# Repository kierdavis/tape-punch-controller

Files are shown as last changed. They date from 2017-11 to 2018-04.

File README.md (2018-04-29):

# Tape Punch Controller

This repository contains the source code and CAD designs used for my university third year individual project.

The project involves designing a system that can interface a restored [Teletype BPRE-type High Speed Tape Punch][tapepunch] to a modern computer over USB.

## Repository Layout

- [`/firmware`][repo-firmware]: source code of the firmware running on the microcontroller
- [`/pcb`][repo-pcb]: design files for the PCB used in the device
- [`/mechanical`][repo-mechanical]: design files for various laser-cut parts

[tapepunch]: http://www.computinghistory.org.uk/det/2312/teletype-brpe-20-high-speed-tape-punch/
[repo-firmware]: https://github.com/kierdavis/tape-punch-controller/tree/master/firmware
[repo-pcb]: https://github.com/kierdavis/tape-punch-controller/tree/master/pcb
[repo-mechanical]: https://github.com/kierdavis/tape-punch-controller/tree/master/mechanical

## Branches

Two main Git branches are used with this repository: `master` and `stable`. New development occurs on `master`; when it has been tested and is deemed ready to ship to the client, it is merged into `stable`. `stable` should be a reflection of the version currently in use by the client.

## License

The contents of this repository are licensed under the terms of the MIT license. See the [LICENSE](LICENSE) file for more details.

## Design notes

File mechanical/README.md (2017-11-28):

# Tape Punch Controller Laser Cutter Designs

These files are in DXF format, readable by [librecad][librecad]. Some designs also have older versions created in 
[FreeCAD][freecad], which I stopped using since it crashed too much.

Part designs in this directory are:

* `back-panel`: a cover for the cavity in the rear of the tape punch's case through which the power and data cables are 
wired. This is to reduce the risk of injury resulting from exposed live wiring.
* `psu-cover`: a minimal cover for the exposed live terminals on the [28V power supply unit][psu]. This is only for 
development; suitable protection will be built into the final product's case design.

[psu]: https://uk.rs-online.com/web/p/-/7772869/
[librecad]: http://librecad.org/cms/home.html
[freecad]: https://www.freecadweb.org/

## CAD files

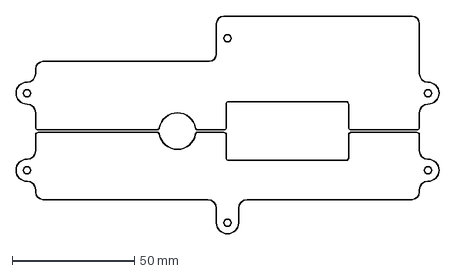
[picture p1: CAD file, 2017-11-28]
mechanical/back-panel/back-panel-rev3.dxf
173.0 x 89.0 mm

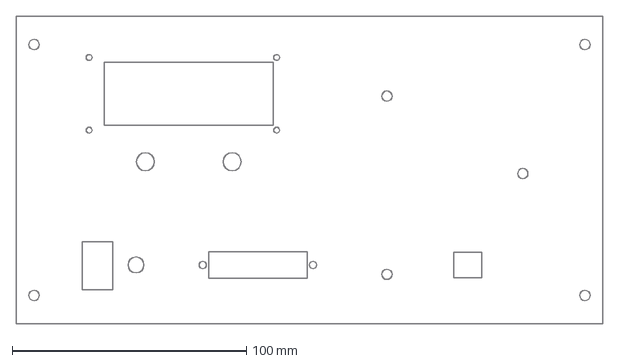
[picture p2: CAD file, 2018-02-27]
mechanical/chassis/front.dxf
250.0 x 131.0 mm

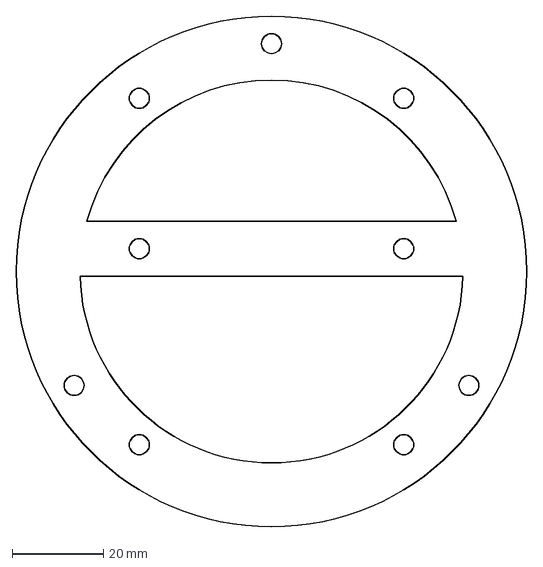
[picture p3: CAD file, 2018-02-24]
mechanical/pcb-holder/pcb-holder.dxf
112.0 x 112.0 mm

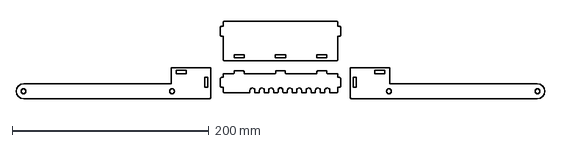
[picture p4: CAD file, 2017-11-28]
mechanical/psu-cover/psu-cover-rev1.dxf
537.0 x 78.5 mm

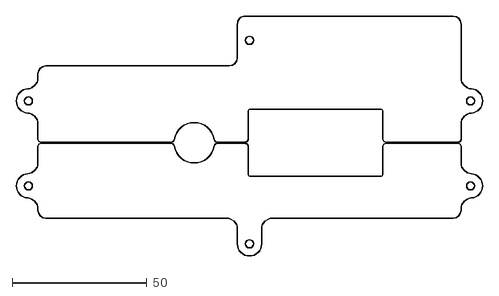
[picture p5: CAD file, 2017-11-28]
mechanical/back-panel/back-panel-rev2-export.dxf
173.0 x 89.0

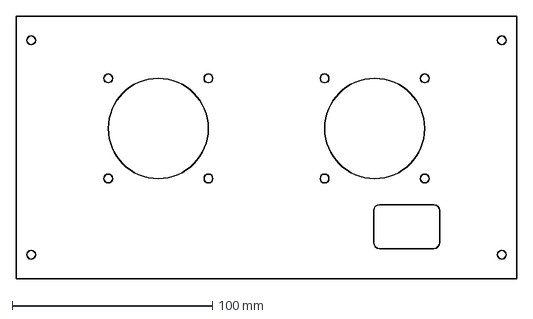
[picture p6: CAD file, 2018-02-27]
mechanical/chassis/rear.dxf
250.0 x 131.0 mm

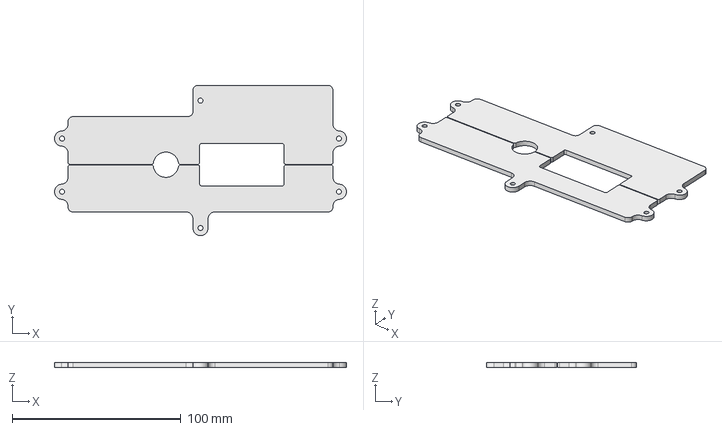
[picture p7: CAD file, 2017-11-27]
mechanical/back-panel/back-panel-rev2.fcstd
173.0 x 89.0 x 3.00 mm

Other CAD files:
mechanical/back-panel/back-panel-rev1.fcstd

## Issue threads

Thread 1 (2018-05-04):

Fix regulator footprint on PCB

kierdavis, 2018-05-04:
The PCB currently uses a standard TO-220 footprint for the 3.3V and 15V regulators, but the components are actually quite a bit larger. They could still be soldered, albeit at a funky angle since one side has to sit on top of the decoupling capacitor.

To fix this, a custom footprint with adequate clearance should be used, and the PCB layout adjusted appropriately.

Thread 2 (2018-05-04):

Fix LCD contrast voltage

kierdavis, 2018-05-04:
As a result of someone's impeccable datasheet-reading skills, the circuit currently allows the LCD's contrast voltage (`Vdd - V0`) to be adjusted between 0V and 3.3V, but the [datasheet](http://docs-europe.electrocomponents.com/webdocs/1548/0900766b815480c9.pdf) says the LCD expects between 4.3V and 4.7V.

This could be fixed by increasing Vdd (e.g. adding a 5V regulator) or decreasing the minimum V0 (needs a negative voltage supply).

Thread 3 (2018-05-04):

Use LCD's status flag rather than assuming all commands have a fixed duration

kierdavis, 2018-05-04:
This may allow some commands to complete earlier than they do currently, and would generally be considered a better approach.

Doing this involves changing the circuit such that the LCD's R/W pin is no longer tied to ground, but to a microcontroller output. This allows the LCD to be read from as well as written to. The [datasheet](https://www.newhavendisplay.com/app_notes/SPLC780D.pdf) then says that the bit 7 of the byte received from the LCD with `RS = 0` and `R/W = 1` is a 1 if the LCD is busy and will not currently accept commands, or a 0 if the LCD is idle and can accept commands.

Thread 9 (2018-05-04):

Design and implement a streaming interface

kierdavis, 2018-05-04:
Using Mass Storage conveniently allows the device to be used without needing to install any custom software on the PC it is used with; however it sets a hard limit on the size of a file that can be transferred. Implementing a stream-based interface (e.g. USB CDC or a custom device class) would step around this problem, and would likely facilitate implementing #8.

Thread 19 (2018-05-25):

Remove USB sense circuitry

kierdavis, 2018-05-25:
Ultimately this wasn't needed since LUFA does a good enough job of detecting when the USB cable is plugged/unplugged. It's therefore unnecessary and should be removed from the PCB.

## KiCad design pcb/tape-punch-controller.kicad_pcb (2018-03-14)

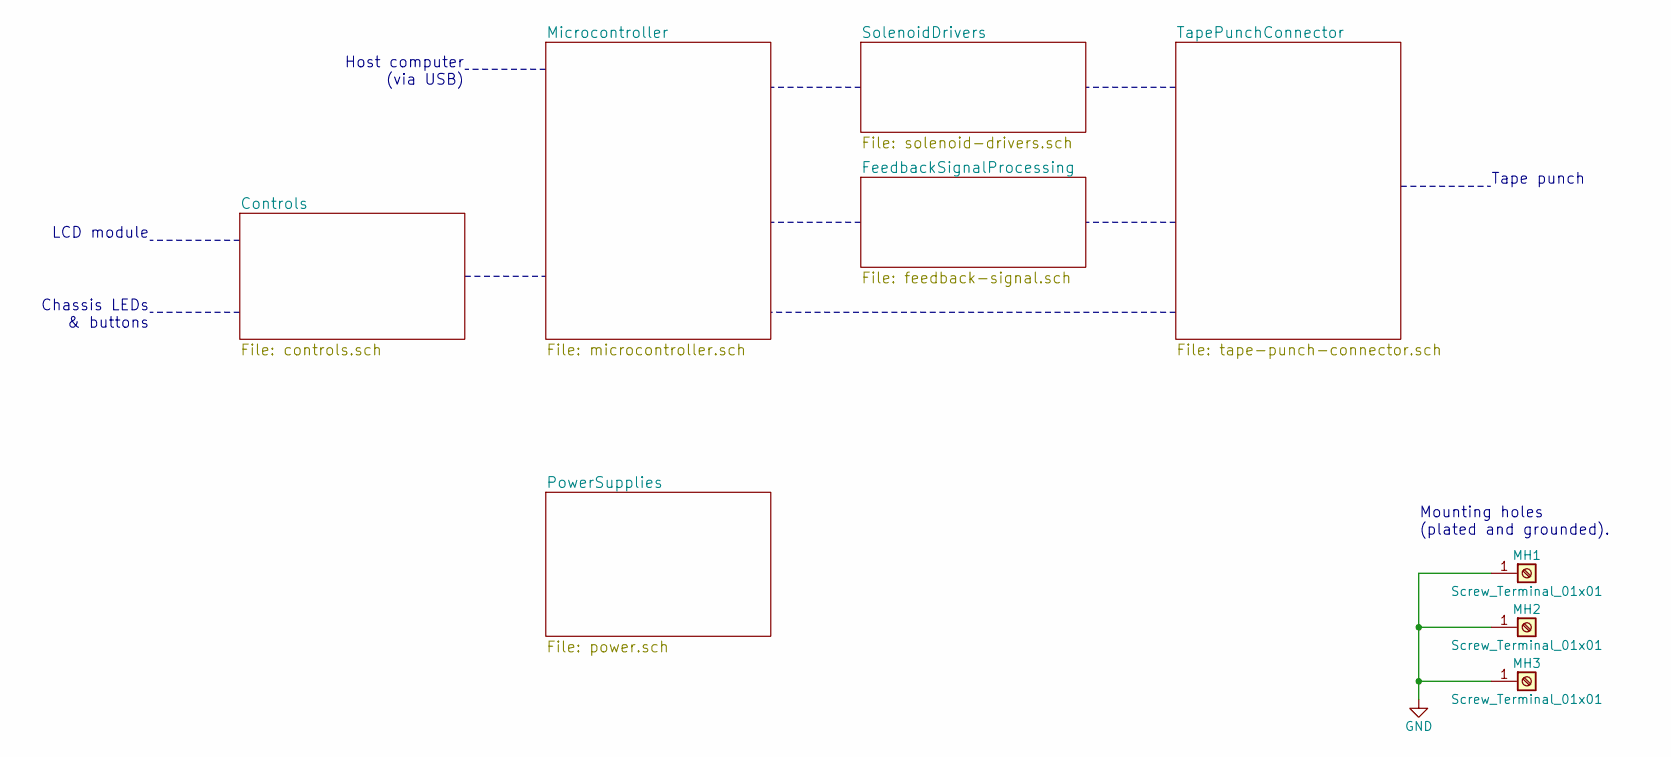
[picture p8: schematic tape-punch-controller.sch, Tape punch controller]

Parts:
MH1, MH2, MH3: Screw_Terminal_01x01; MountingHole_4.3mm_M4_Pad

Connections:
GND: MH1.1, MH2.1, MH3.1; also elsewhere on the board

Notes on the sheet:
Mounting holes (plated and grounded).
LCD module
Chassis LEDs & buttons
Host computer (via USB)
Tape punch

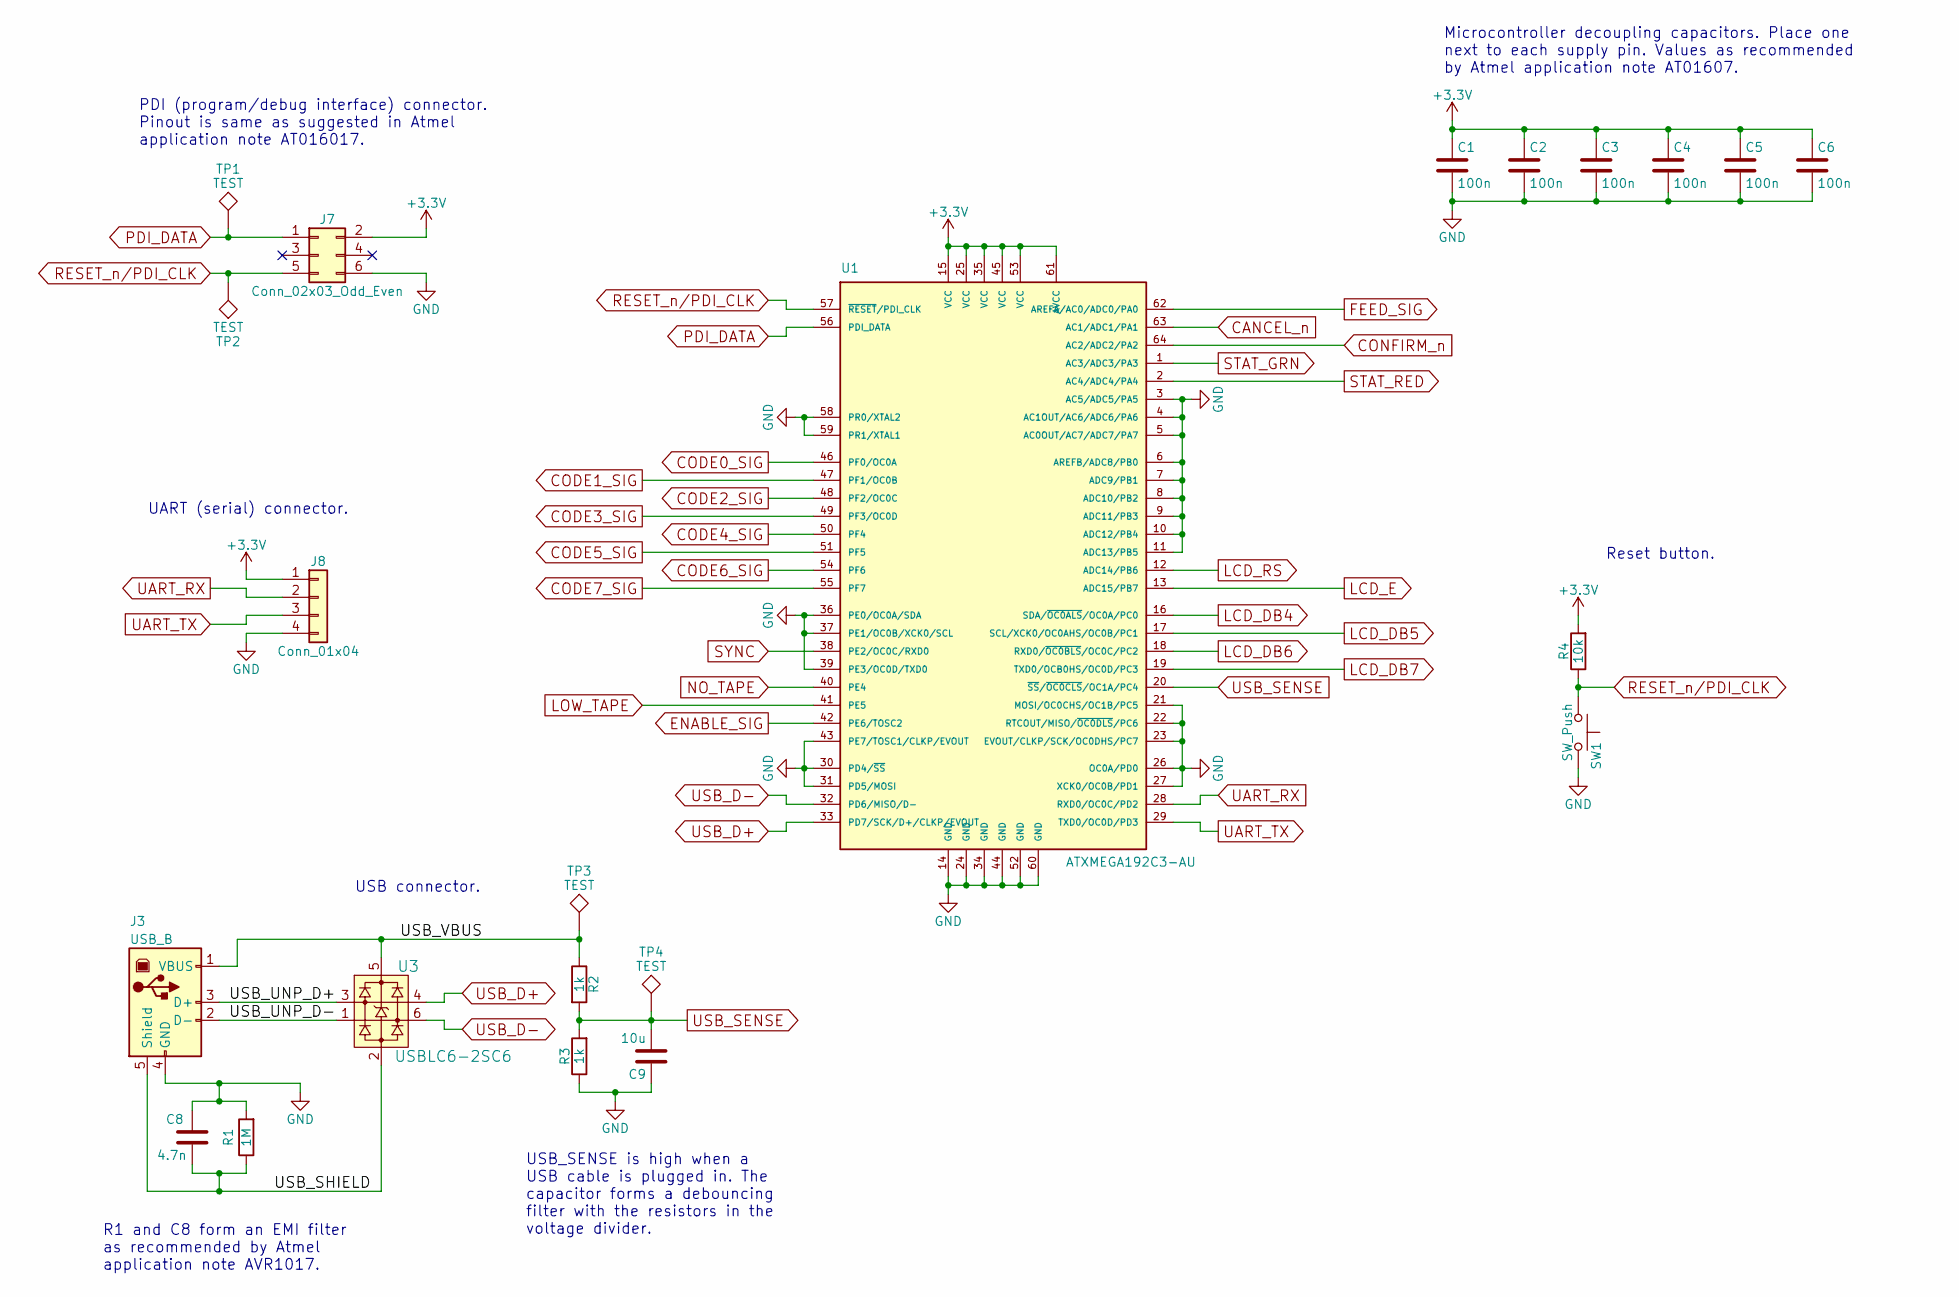
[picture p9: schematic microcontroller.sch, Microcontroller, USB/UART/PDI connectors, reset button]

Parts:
C1, C2, C3, C4, C5, C6: 100n; C_0805_HandSoldering
C8: 4.7n; C_0805_HandSoldering
C9: 10u; C_1206_HandSoldering
J3: USB_B; Multicomp_MC32597
J7: Conn_02x03_Odd_Even; Pin_Header_Straight_2x03_Pitch2.54mm
J8: Conn_01x04; Pin_Header_Straight_1x04_Pitch2.54mm
R1: 1M; R_0805_HandSoldering
R2, R3: 1k; R_0805_HandSoldering
R4: 10k; R_0805_HandSoldering
SW1: SW_Push; SW_Tactile_SPST_Angled_PTS645Vx58-2LFS
TP1, TP2, TP3, TP4: TEST; Measurement_Point_Round-SMD-Pad_Small
U1: ATXMEGA192C3-AU; TQFP-64_14x14mm_Pitch0.8mm
U3: USBLC6-2SC6; SOT-23-6_Handsoldering

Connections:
+3V3: C1.1, C2.1, C3.1, C4.1, C5.1, C6.1, J7.2, J8.1, R4.2, U1.15 (VCC), U1.25 (VCC), U1.35 (VCC), U1.45 (VCC), U1.53 (VCC), U1.61 (AVCC); also elsewhere on the board
/Microcontroller/USB_SHIELD: C8.2, J3.5 (Shield), R1.1, U3.2 (GND)
/Microcontroller/USB_UNP_D+: J3.3 (D+), U3.3 (D+)
/Microcontroller/USB_UNP_D-: J3.2 (D-), U3.1 (D-)
/Microcontroller/USB_VBUS: J3.1 (VBUS), R2.1, TP3.1, U3.5 (VBUS)
CANCEL_n: U1.63 (AC1/ADC1/PA1); also elsewhere on the board
CODE0_SIG: U1.46 (PF0/OC0A); also elsewhere on the board
CODE1_SIG: U1.47 (PF1/OC0B); also elsewhere on the board
CODE2_SIG: U1.48 (PF2/OC0C); also elsewhere on the board
CODE3_SIG: U1.49 (PF3/OC0D); also elsewhere on the board
CODE4_SIG: U1.50 (PF4); also elsewhere on the board
CODE5_SIG: U1.51 (PF5); also elsewhere on the board
CODE6_SIG: U1.54 (PF6); also elsewhere on the board
CODE7_SIG: U1.55 (PF7); also elsewhere on the board
CONFIRM_n: U1.64 (AC2/ADC2/PA2); also elsewhere on the board
ENABLE_SIG: U1.42 (PE6/TOSC2); also elsewhere on the board
FEED_SIG: U1.62 (AREFA/AC0/ADC0/PA0); also elsewhere on the board
GND: C1.2, C2.2, C3.2, C4.2, C5.2, C6.2, C8.1, C9.1, J3.4 (GND), J7.6, J8.4, R1.2, R3.1, SW1.2, U1.3 (AC5/ADC5/PA5), U1.4 (AC1OUT/AC6/ADC6/PA6), U1.5 (AC0OUT/AC7/ADC7/PA7), U1.6 (AREFB/ADC8/PB0), U1.7 (ADC9/PB1), U1.8 (ADC10/PB2), U1.9 (ADC11/PB3), U1.10 (ADC12/PB4), U1.11 (ADC13/PB5), U1.14 (GND), U1.21 (MOSI/OC0CHS/OC1B/PC5), U1.22 (RTCOUT/MISO/~OC0DLS~/PC6), U1.23 (EVOUT/CLKP/SCK/OC0DHS/PC7), U1.24 (GND), U1.26 (OC0A/PD0), U1.27 (XCK0/OC0B/PD1), U1.30 (PD4/~SS~), U1.31 (PD5/MOSI), U1.34 (GND), U1.36 (PE0/OC0A/SDA), U1.37 (PE1/OC0B/XCK0/SCL), U1.39 (PE3/OC0D/TXD0), U1.43 (PE7/TOSC1/CLKP/EVOUT), U1.44 (GND), U1.52 (GND), U1.58 (PR0/XTAL2), U1.59 (PR1/XTAL1), U1.60 (GND); also elsewhere on the board
LCD_DB4: U1.16 (SDA/~OC0ALS~/OC0A/PC0); also elsewhere on the board
LCD_DB5: U1.17 (SCL/XCK0/OC0AHS/OC0B/PC1); also elsewhere on the board
LCD_DB6: U1.18 (RXD0/~OC0BLS~/OC0C/PC2); also elsewhere on the board
LCD_DB7: U1.19 (TXD0/OCB0HS/OC0D/PC3); also elsewhere on the board
LCD_E: U1.13 (ADC15/PB7); also elsewhere on the board
LCD_RS: U1.12 (ADC14/PB6); also elsewhere on the board
LOW_TAPE: U1.41 (PE5); also elsewhere on the board
NO_TAPE: U1.40 (PE4); also elsewhere on the board
PDI_DATA: J7.1, TP1.1, U1.56 (PDI_DATA)
RESET_n/PDI_CLK: J7.5, R4.1, SW1.1, TP2.1, U1.57 (~RESET~/PDI_CLK)
STAT_GRN: U1.1 (AC3/ADC3/PA3); also elsewhere on the board
STAT_RED: U1.2 (AC4/ADC4/PA4); also elsewhere on the board
SYNC: U1.38 (PE2/OC0C/RXD0); also elsewhere on the board
UART_RX: J8.2, U1.28 (RXD0/OC0C/PD2)
UART_TX: J8.3, U1.29 (TXD0/OC0D/PD3)
USB_D+: U1.33 (PD7/SCK/D+/CLKP/EVOUT), U3.4 (D+)
USB_D-: U1.32 (PD6/MISO/D-), U3.6 (D-)
USB_SENSE: C9.2, R2.2, R3.2, TP4.1, U1.20 (~SS~/~OC0CLS~/OC1A/PC4)

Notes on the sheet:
Microcontroller decoupling capacitors. Place one next to each supply pin. Values as recommended by Atmel application note AT01607.
UART (serial) connector.
PDI (program/debug interface) connector. Pinout is same as suggested in Atmel application note AT016017.
USB connector.
USB_SENSE is high when a USB cable is plugged in. The capacitor forms a debouncing filter with the resistors in the voltage divider.
R1 and C8 form an EMI filter as recommended by Atmel application note AVR1017.
Reset button.

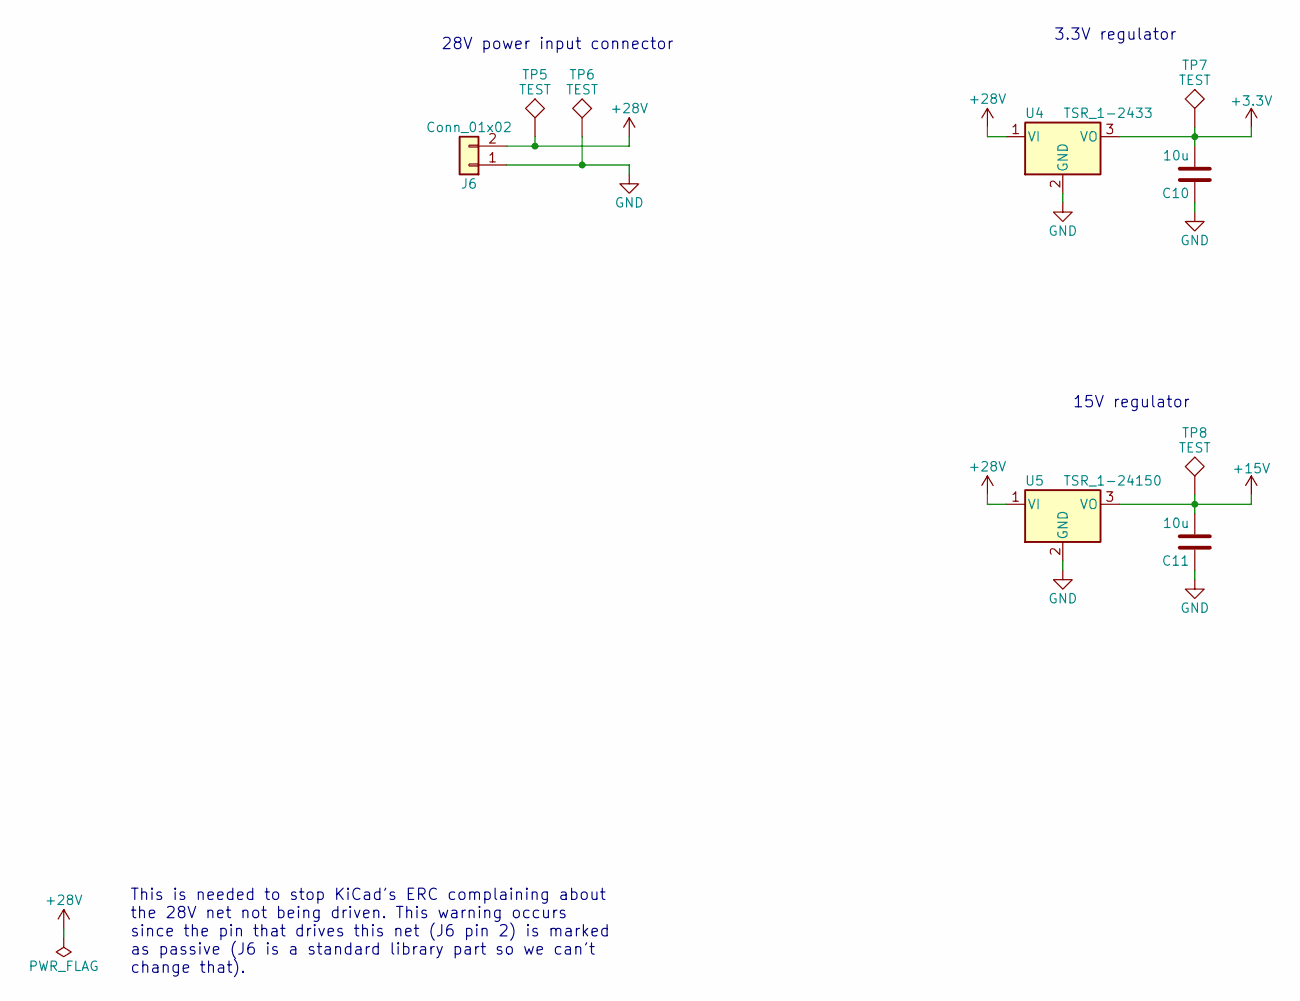
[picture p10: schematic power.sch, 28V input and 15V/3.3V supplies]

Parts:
C10, C11: 10u; C_1206_HandSoldering
J6: Conn_01x02; Multicomp_MC000048
TP5, TP6, TP7, TP8: TEST; Measurement_Point_Round-SMD-Pad_Small
U4: TSR_1-2433; TO-220-3_Vertical
U5: TSR_1-24150; TO-220-3_Vertical

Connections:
+3V3: C10.2, TP7.1, U4.3 (VO); also elsewhere on the board
+15V: C11.2, TP8.1, U5.3 (VO); also elsewhere on the board
+28V: J6.2, TP5.1, U4.1 (VI), U5.1 (VI); also elsewhere on the board
GND: C10.1, C11.1, J6.1, TP6.1, U4.2 (GND), U5.2 (GND); also elsewhere on the board

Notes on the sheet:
28V power input connector
3.3V regulator
15V regulator
This is needed to stop KiCad's ERC complaining about the 28V net not being driven. This warning occurs since the pin that drives this net (J6 pin 2) is marked as passive (J6 is a standard library part so we can't change that).

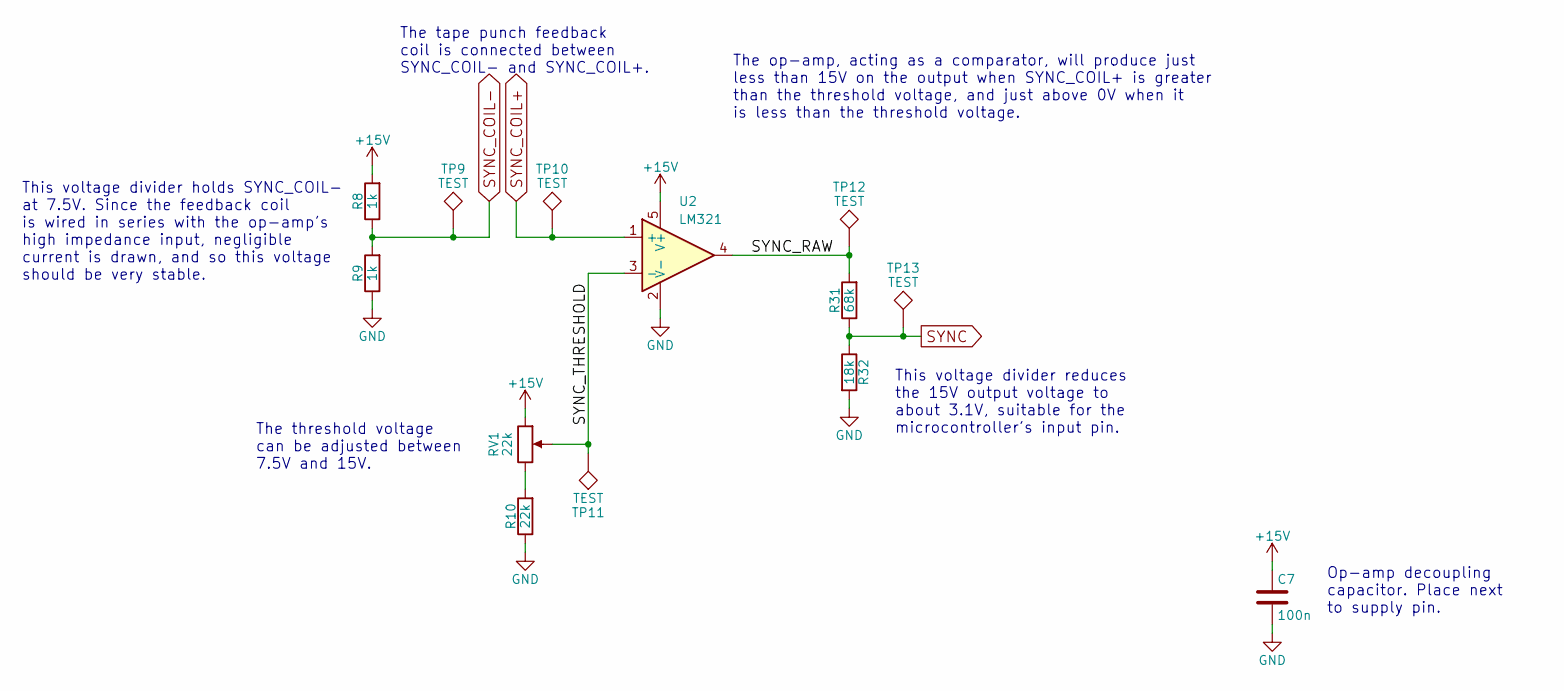
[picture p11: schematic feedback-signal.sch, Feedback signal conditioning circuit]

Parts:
C7: 100n; C_0805_HandSoldering
R8, R9: 1k; R_0805_HandSoldering
R10: 22k; R_0805_HandSoldering
R31: 68k; R_0805_HandSoldering
R32: 18k; R_0805_HandSoldering
RV1: 22k; Citec_CB10LV103M
TP9, TP10, TP11, TP12, TP13: TEST; Measurement_Point_Round-SMD-Pad_Small
U2: LM321; SOT-23-5_HandSoldering

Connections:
+15V: C7.1, R8.2, RV1.1, U2.5 (V+); also elsewhere on the board
/FeedbackSignalProcessing/SYNC_RAW: R31.2, TP12.1, U2.4
/FeedbackSignalProcessing/SYNC_THRESHOLD: RV1.2, TP11.1, U2.3 (-)
GND: C7.2, R9.1, R10.1, R32.2, U2.2 (V-); also elsewhere on the board
unnamed: R10.2, RV1.3
SYNC: R31.1, R32.1, TP13.1; also elsewhere on the board
SYNC_COIL+: TP10.1, U2.1 (+); also elsewhere on the board
SYNC_COIL-: R8.1, R9.2, TP9.1; also elsewhere on the board

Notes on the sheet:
Op-amp decoupling capacitor. Place next to supply pin.
The tape punch feedback coil is connected between SYNC_COIL- and SYNC_COIL+.
This voltage divider holds SYNC_COIL- at 7.5V. Since the feedback coil is wired in series with the op-amp's high impedance input, negligible current is drawn, and so this voltage should be very stable.
The threshold voltage can be adjusted between 7.5V and 15V.
The op-amp, acting as a comparator, will produce just less than 15V on the output when SYNC_COIL+ is greater than the threshold voltage, and just above 0V when it is less than the threshold voltage.
This voltage divider reduces the 15V output voltage to about 3.1V, suitable for the microcontroller's input pin.

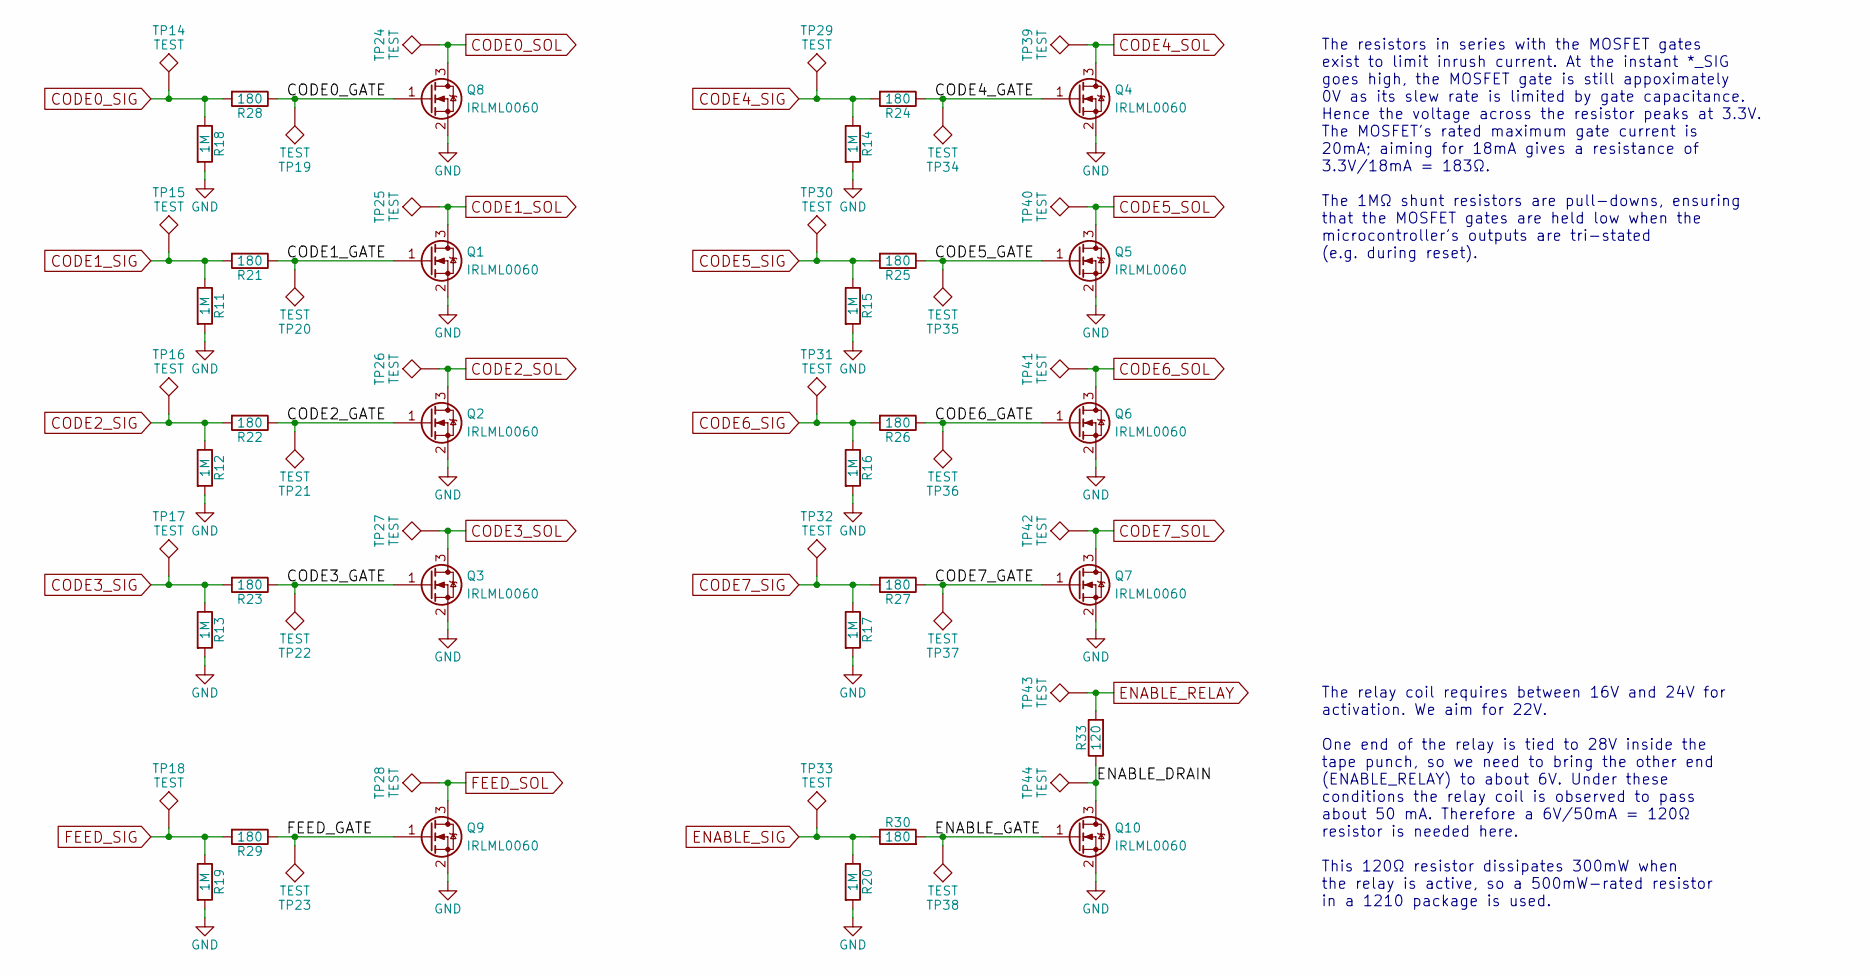
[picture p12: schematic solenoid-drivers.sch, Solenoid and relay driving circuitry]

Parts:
Q1, Q2, Q3, Q4, Q5, Q6, Q7, Q8, Q9, Q10: IRLML0060; SOT-23_Handsoldering
R11, R12, R13, R14, R15, R16, R17, R18, R19, R20: 1M; R_0805_HandSoldering
R21, R22, R23, R24, R25, R26, R27, R28, R29, R30: 180; R_0805_HandSoldering
R33: 120; R_1210_HandSoldering
TP14, TP15, TP16, TP17, TP18, TP19, TP20, TP21, TP22, TP23, TP24, TP25, TP26, TP27, TP28, TP29, TP30, TP31, TP32, TP33, TP34, TP35, TP36, TP37, TP38, TP39, TP40, TP41, TP42, TP43, TP44: TEST; Measurement_Point_Round-SMD-Pad_Small

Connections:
/SolenoidDrivers/CODE0_GATE: Q8.1 (G), R28.1, TP19.1
/SolenoidDrivers/CODE1_GATE: Q1.1 (G), R21.1, TP20.1
/SolenoidDrivers/CODE2_GATE: Q2.1 (G), R22.1, TP21.1
/SolenoidDrivers/CODE3_GATE: Q3.1 (G), R23.1, TP22.1
/SolenoidDrivers/CODE4_GATE: Q4.1 (G), R24.1, TP34.1
/SolenoidDrivers/CODE5_GATE: Q5.1 (G), R25.1, TP35.1
/SolenoidDrivers/CODE6_GATE: Q6.1 (G), R26.1, TP36.1
/SolenoidDrivers/CODE7_GATE: Q7.1 (G), R27.1, TP37.1
/SolenoidDrivers/ENABLE_DRAIN: Q10.3 (D), R33.1, TP44.1
/SolenoidDrivers/ENABLE_GATE: Q10.1 (G), R30.2, TP38.1
/SolenoidDrivers/FEED_GATE: Q9.1 (G), R29.1, TP23.1
CODE0_SIG: R18.1, R28.2, TP14.1; also elsewhere on the board
CODE0_SOL: Q8.3 (D), TP24.1; also elsewhere on the board
CODE1_SIG: R11.1, R21.2, TP15.1; also elsewhere on the board
CODE1_SOL: Q1.3 (D), TP25.1; also elsewhere on the board
CODE2_SIG: R12.1, R22.2, TP16.1; also elsewhere on the board
CODE2_SOL: Q2.3 (D), TP26.1; also elsewhere on the board
CODE3_SIG: R13.1, R23.2, TP17.1; also elsewhere on the board
CODE3_SOL: Q3.3 (D), TP27.1; also elsewhere on the board
CODE4_SIG: R14.1, R24.2, TP29.1; also elsewhere on the board
CODE4_SOL: Q4.3 (D), TP39.1; also elsewhere on the board
CODE5_SIG: R15.1, R25.2, TP30.1; also elsewhere on the board
CODE5_SOL: Q5.3 (D), TP40.1; also elsewhere on the board
CODE6_SIG: R16.1, R26.2, TP31.1; also elsewhere on the board
CODE6_SOL: Q6.3 (D), TP41.1; also elsewhere on the board
CODE7_SIG: R17.1, R27.2, TP32.1; also elsewhere on the board
CODE7_SOL: Q7.3 (D), TP42.1; also elsewhere on the board
ENABLE_RELAY: R33.2, TP43.1; also elsewhere on the board
ENABLE_SIG: R20.1, R30.1, TP33.1; also elsewhere on the board
FEED_SIG: R19.1, R29.2, TP18.1; also elsewhere on the board
FEED_SOL: Q9.3 (D), TP28.1; also elsewhere on the board
GND: Q1.2 (S), Q2.2 (S), Q3.2 (S), Q4.2 (S), Q5.2 (S), Q6.2 (S), Q7.2 (S), Q8.2 (S), Q9.2 (S), Q10.2 (S), R11.2, R12.2, R13.2, R14.2, R15.2, R16.2, R17.2, R18.2, R19.2, R20.2; also elsewhere on the board

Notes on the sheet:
The resistors in series with the MOSFET gates exist to limit inrush current. At the instant *_SIG goes high, the MOSFET gate is still appoximately 0V as its slew rate is limited by gate capacitance. Hence the voltage across the resistor peaks at 3.3V. The MOSFET's rated maximum gate current is 20mA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
The relay coil requires between 16V and 24V for activation. We aim for 22V. One end of the relay is tied to 28V inside the tape punch, so we need to bring the other end (ENABLE_RELAY) to about 6V. Under these conditions the relay coil is observed to pass about 50 mA. Therefore a 6V/50mA = 120Ω resi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

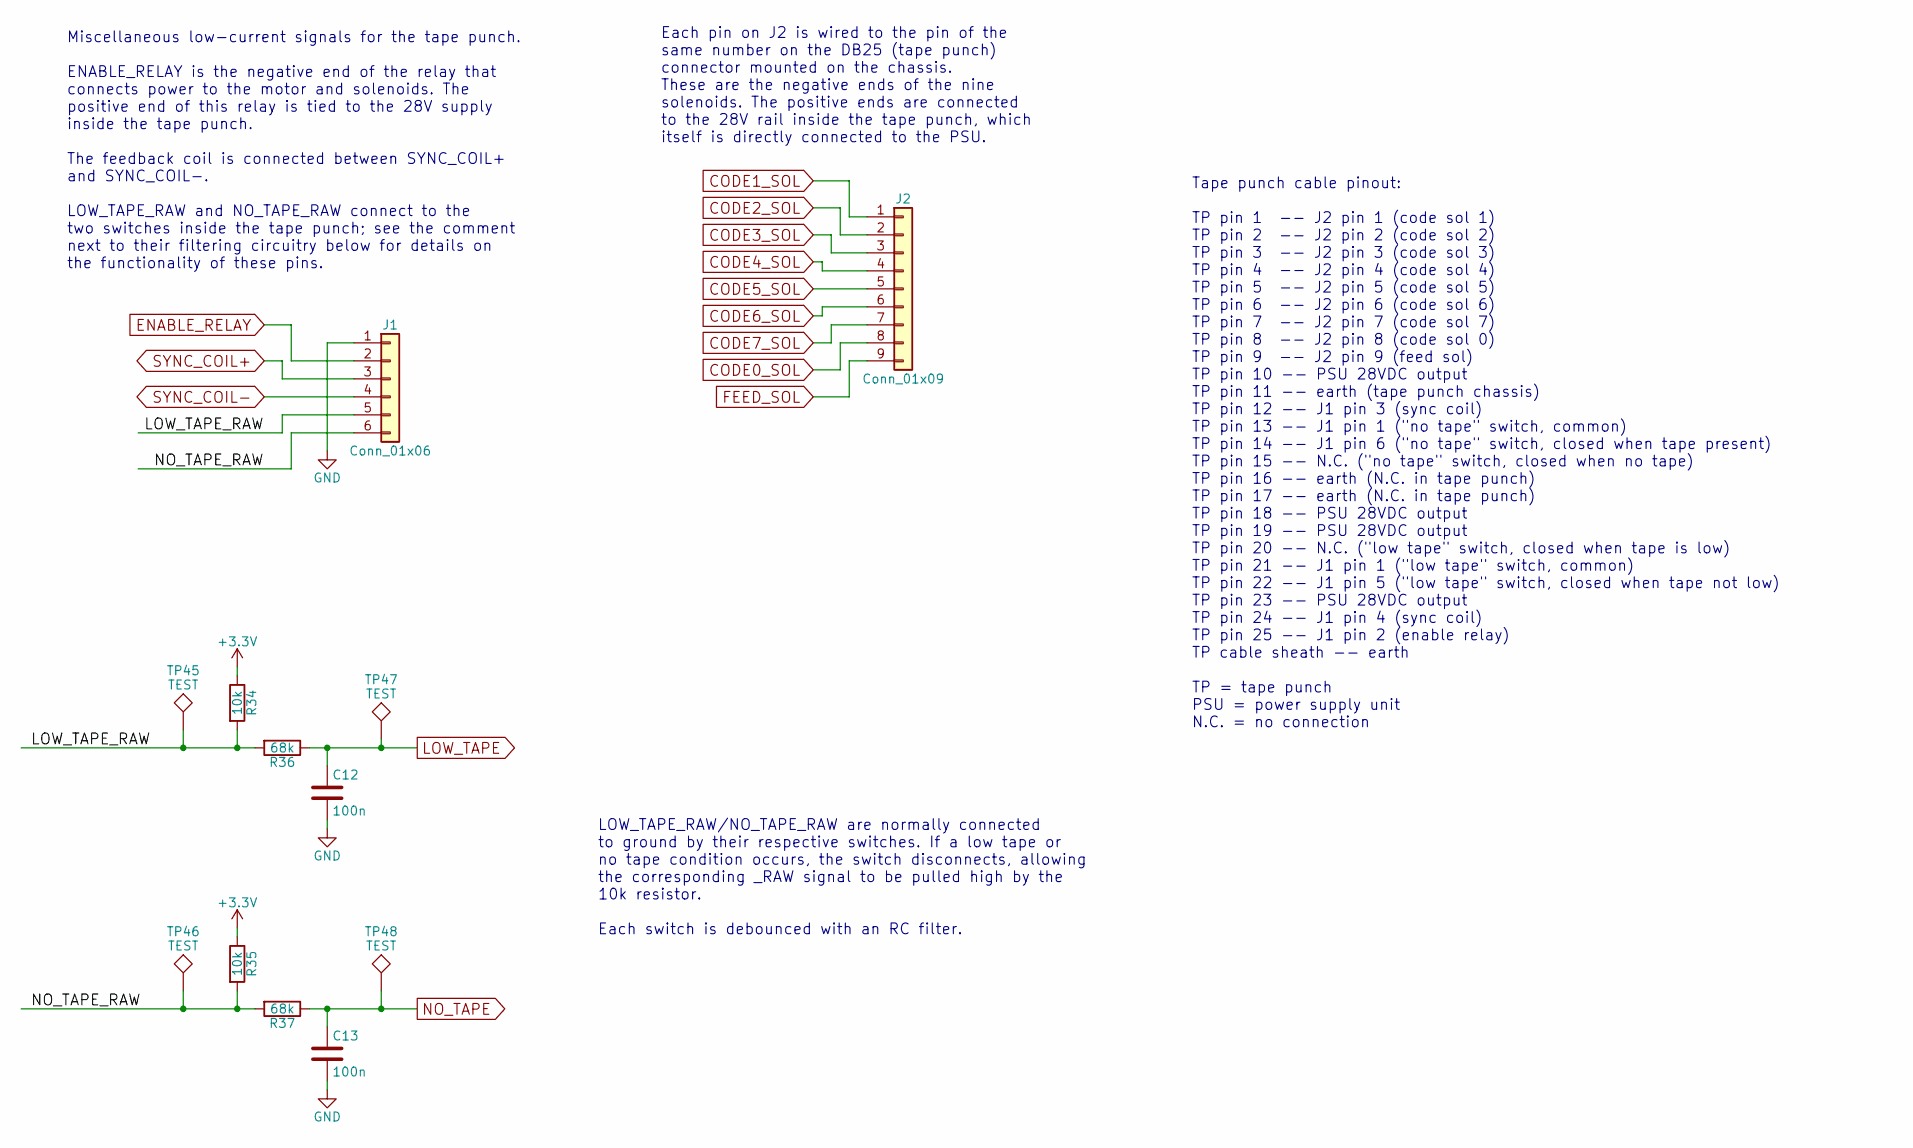
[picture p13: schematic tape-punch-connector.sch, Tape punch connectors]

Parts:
C12, C13: 100n; C_0805_HandSoldering
J1: Conn_01x06; Amphenol_T821106A1S100CEU
J2: Conn_01x09; Weidmuller_1234610000
R34, R35: 10k; R_0805_HandSoldering
R36, R37: 68k; R_0805_HandSoldering
TP45, TP46, TP47, TP48: TEST; Measurement_Point_Round-SMD-Pad_Small

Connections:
+3V3: R34.1, R35.1; also elsewhere on the board
/TapePunchConnector/LOW_TAPE_RAW: J1.5, R34.2, R36.2, TP45.1
/TapePunchConnector/NO_TAPE_RAW: J1.6, R35.2, R37.2, TP46.1
CODE0_SOL: J2.8; also elsewhere on the board
CODE1_SOL: J2.1; also elsewhere on the board
CODE2_SOL: J2.2; also elsewhere on the board
CODE3_SOL: J2.3; also elsewhere on the board
CODE4_SOL: J2.4; also elsewhere on the board
CODE5_SOL: J2.5; also elsewhere on the board
CODE6_SOL: J2.6; also elsewhere on the board
CODE7_SOL: J2.7; also elsewhere on the board
ENABLE_RELAY: J1.2; also elsewhere on the board
FEED_SOL: J2.9; also elsewhere on the board
GND: C12.2, C13.2, J1.1; also elsewhere on the board
LOW_TAPE: C12.1, R36.1, TP47.1; also elsewhere on the board
NO_TAPE: C13.1, R37.1, TP48.1; also elsewhere on the board
SYNC_COIL+: J1.3; also elsewhere on the board
SYNC_COIL-: J1.4; also elsewhere on the board

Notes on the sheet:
LOW_TAPE_RAW/NO_TAPE_RAW are normally connected to ground by their respective switches. If a low tape or no tape condition occurs, the switch disconnects, allowing the corresponding _RAW signal to be pulled high by the 10k resistor. Each switch is debounced with an RC filter.
Each pin on J2 is wired to the pin of the same number on the DB25 (tape punch) connector mounted on the chassis. These are the negative ends of the nine solenoids. The positive ends are connected to the 28V rail inside the tape punch, which itself is directly connected to the PSU.
Tape punch cable pinout: TP pin 1 -- J2 pin 1 (code sol 1) TP pin 2 -- J2 pin 2 (code sol 2) TP pin 3 -- J2 pin 3 (code sol 3) TP pin 4 -- J2 pin 4 (code sol 4) TP pin 5 -- J2 pin 5 (code sol 5) TP pin 6 -- J2 pin 6 (code sol 6) TP pin 7 -- J2 pin 7 (code sol 7) TP pin 8 -- J2 pin 8 (code sol 0) TP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
Miscellaneous low-current signals for the tape punch. ENABLE_RELAY is the negative end of the relay that connects power to the motor and solenoids. The positive end of this relay is tied to the 28V supply inside the tape punch. The feedback coil is connected between SYNC_COIL+ and SYNC_COIL-. LOW_T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

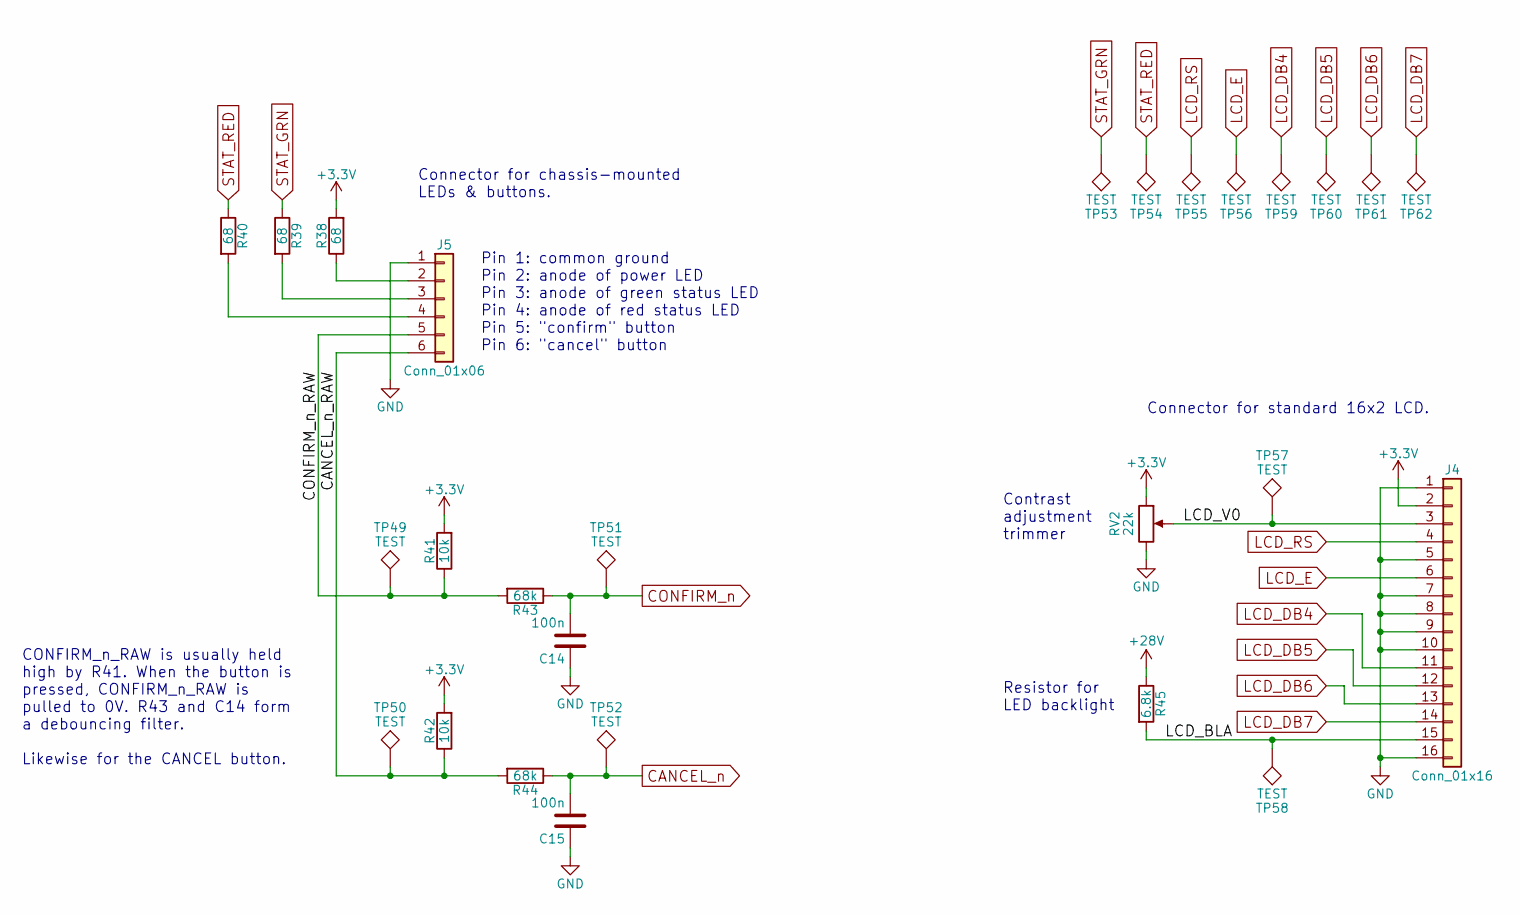
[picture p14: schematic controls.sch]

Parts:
C14, C15: 100n; C_0805_HandSoldering
J4: Conn_01x16; Amphenol_T821116A1S100CEU
J5: Conn_01x06; Amphenol_T821106A1S100CEU
R38, R39, R40: 68; R_0805_HandSoldering
R41, R42: 10k; R_0805_HandSoldering
R43, R44: 68k; R_0805_HandSoldering
R45: 6.8k; R_0805_HandSoldering
RV2: 22k; Citec_CB10LV103M
TP49, TP50, TP51, TP52, TP53, TP54, TP55, TP56, TP57, TP58, TP59, TP60, TP61, TP62: TEST; Measurement_Point_Round-SMD-Pad_Small

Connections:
+3V3: J4.2, R38.2, R41.2, R42.2, RV2.1; also elsewhere on the board
+28V: R45.1; also elsewhere on the board
/Controls/CANCEL_n_RAW: J5.6, R42.1, R44.2, TP50.1
/Controls/CONFIRM_n_RAW: J5.5, R41.1, R43.2, TP49.1
/Controls/LCD_BLA: J4.15, R45.2, TP58.1
/Controls/LCD_V0: J4.3, RV2.2, TP57.1
CANCEL_n: C15.2, R44.1, TP52.1; also elsewhere on the board
CONFIRM_n: C14.2, R43.1, TP51.1; also elsewhere on the board
GND: C14.1, C15.1, J4.1, J4.5, J4.7, J4.8, J4.9, J4.10, J4.16, J5.1, RV2.3; also elsewhere on the board
LCD_DB4: J4.11, TP59.1; also elsewhere on the board
LCD_DB5: J4.12, TP60.1; also elsewhere on the board
LCD_DB6: J4.13, TP61.1; also elsewhere on the board
LCD_DB7: J4.14, TP62.1; also elsewhere on the board
LCD_E: J4.6, TP56.1; also elsewhere on the board
LCD_RS: J4.4, TP55.1; also elsewhere on the board
unnamed: J5.2, R38.1
unnamed: J5.3, R39.2
unnamed: J5.4, R40.2
STAT_GRN: R39.1, TP53.1; also elsewhere on the board
STAT_RED: R40.1, TP54.1; also elsewhere on the board

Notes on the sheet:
Contrast adjustment trimmer
Resistor for LED backlight
Connector for standard 16x2 LCD.
Connector for chassis-mounted LEDs & buttons.
Pin 1: common ground Pin 2: anode of power LED Pin 3: anode of green status LED Pin 4: anode of red status LED Pin 5: "confirm" button Pin 6: "cancel" button
CONFIRM_n_RAW is usually held high by R41. When the button is pressed, CONFIRM_n_RAW is pulled to 0V. R43 and C14 form a debouncing filter. Likewise for the CANCEL button.

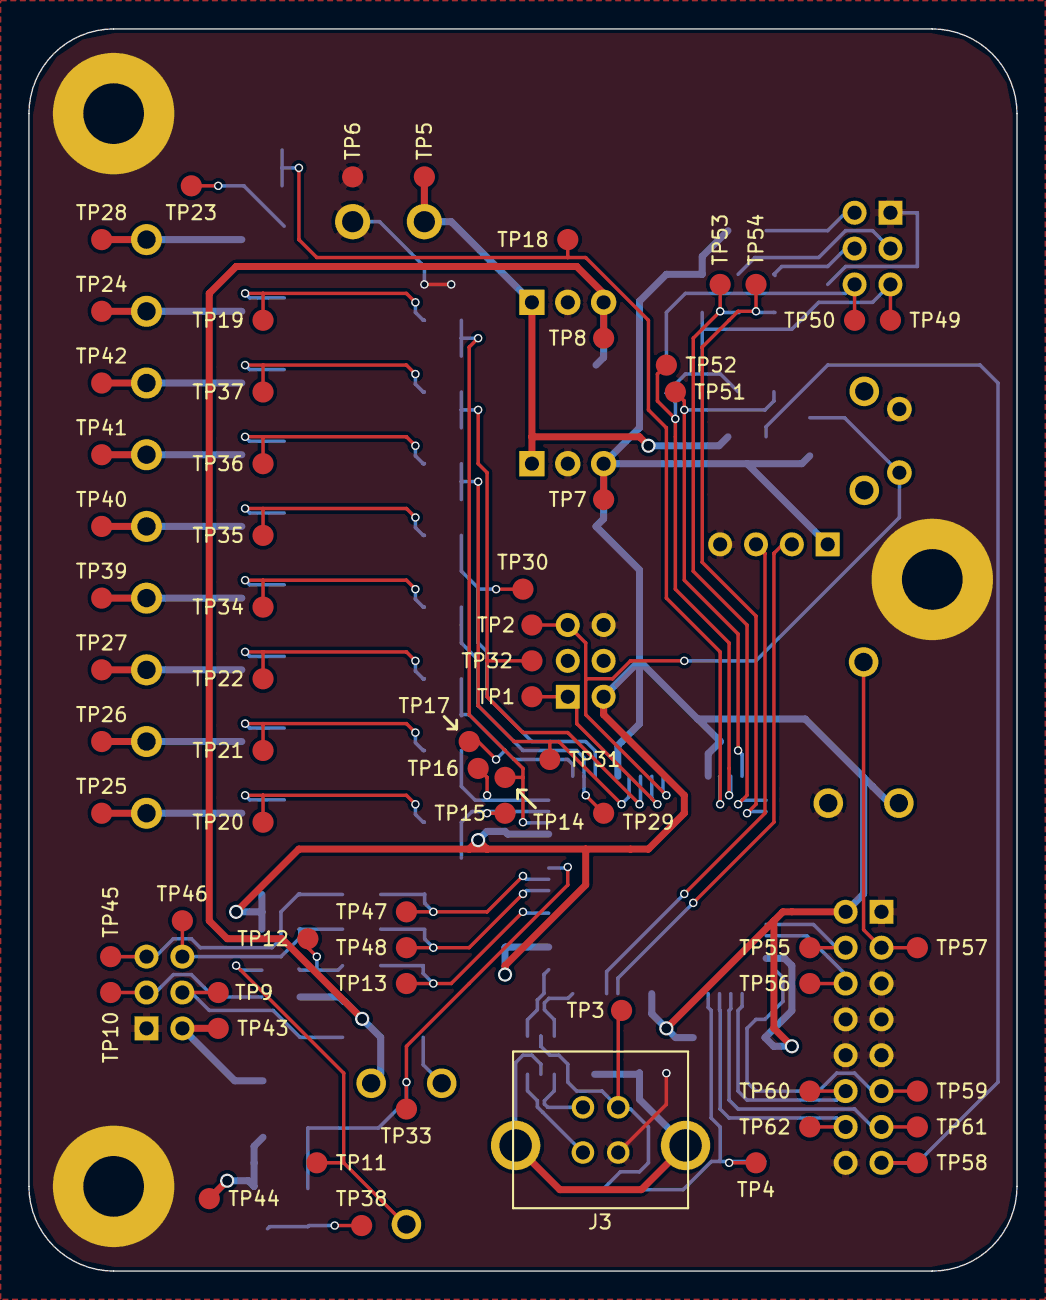
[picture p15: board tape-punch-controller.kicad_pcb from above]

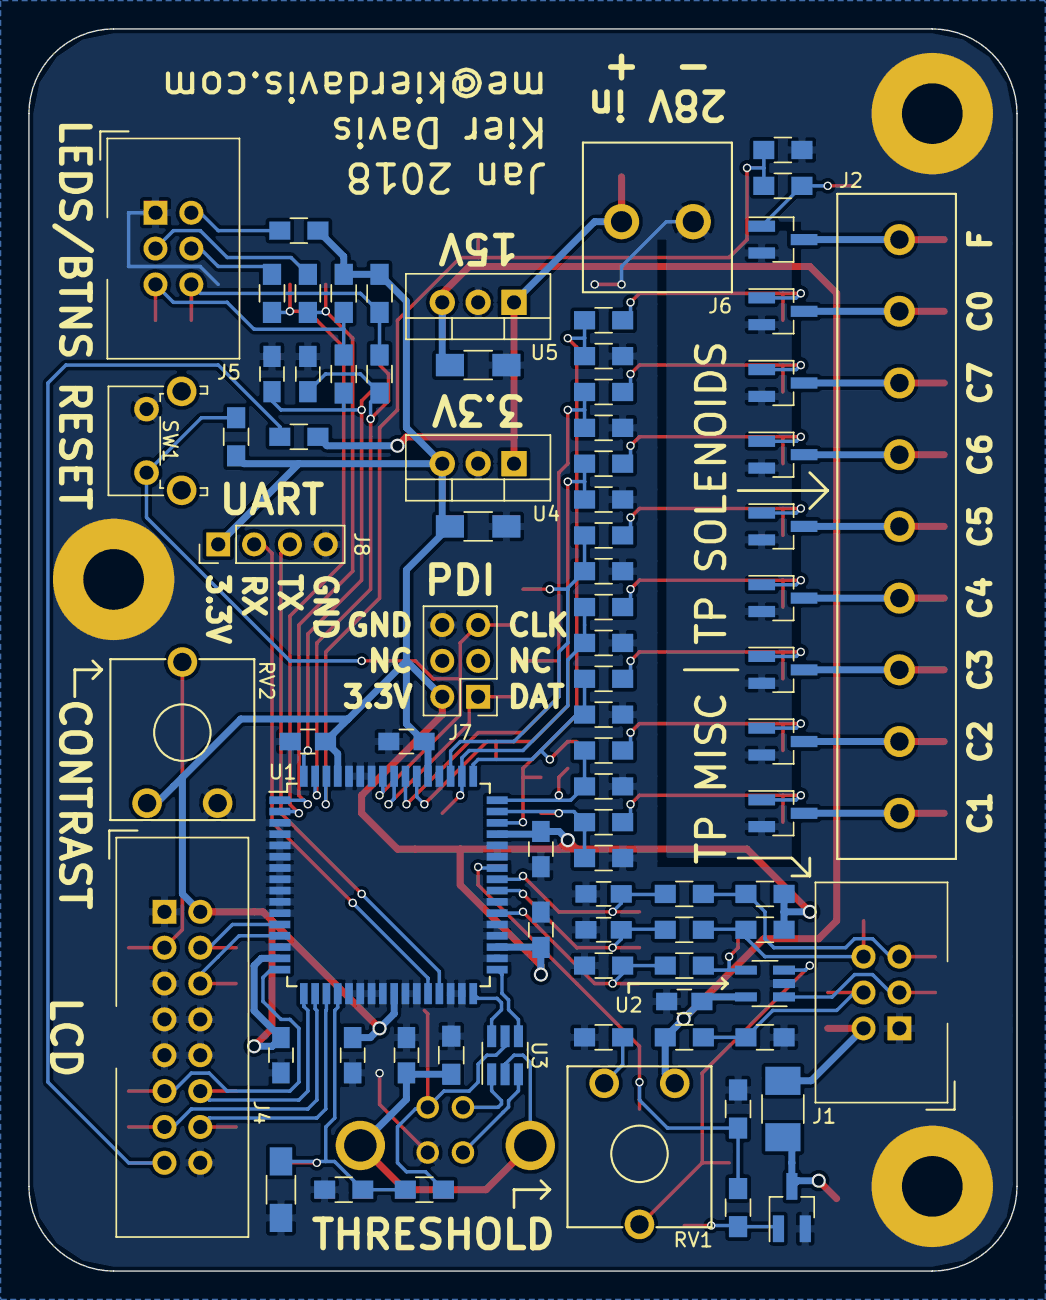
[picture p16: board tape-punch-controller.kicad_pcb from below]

Board: 2 copper layers, 70.0 x 88.0 mm, 148 parts (85 on the bottom side), 73 nets.

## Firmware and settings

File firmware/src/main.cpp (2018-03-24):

#include <avr/interrupt.h>
#include <util/delay.h>

#include "TPC/Application.hpp"
#include "TPC/Log.hpp"
#include "TPC/MicrocontrollerDriver.hpp"
#include "TPC/Scheduler.hpp"

int main() {
  // First stage init.
  TPC::MicrocontrollerDriver::init();
  TPC::Log::init();
  LOG(INFO, "[main] initialising...");

  // Second stage init.
  TPC::MicrocontrollerDriver::logResetSource();
  TPC::Scheduler::init();
  TPC::Application::init();
  sei();
  LOG(IMPORTANT, "[main] ready");

  while (1) {
    TPC::Scheduler::serviceTasks();
  }
}

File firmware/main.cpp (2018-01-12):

#include <stdio.h>
#include <util/delay.h>
#include <avr/interrupt.h>

#include "TapePunch.hpp"

static volatile uint8_t test_data[] = {
  0b10000,
  0b01000,
  0b00100,
  0b00010,
  0b00001,
  0b00010,
  0b00100,
  0b01000,
};

static volatile TapePunch::Job job4(TapePunch::Job::Type::BLANK, 160, nullptr);
static volatile TapePunch::Job job3(TapePunch::Job::Type::DATA,  160, test_data, &job4);
static volatile TapePunch::Job job2(TapePunch::Job::Type::BLANK, 160, nullptr,   &job3);
static volatile TapePunch::Job job1(TapePunch::Job::Type::NOP,   90,  nullptr,   &job2);

int main() {
  TapePunch::init();
  sei();

  TapePunch::queueJobs(&job1);
  TapePunch::setEnabled(true);
  while (TapePunch::busy()) {
    _delay_ms(100);
  }
  TapePunch::setEnabled(false);
}

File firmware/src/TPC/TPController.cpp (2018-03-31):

#include <stdbool.h>
#include <stdint.h>

#include <util/atomic.h>

#include "TPC/Application.hpp"
#include "TPC/Config.hpp"
#include "TPC/Filesystem.hpp"
#include "TPC/Scheduler.hpp"
#include "TPC/Timekeeping.hpp"
#include "TPC/TPController.hpp"
#include "TPC/TPDataProvider.hpp"
#include "TPC/TPMotorDriver.hpp"
#include "TPC/TPSensorsDriver.hpp"
#include "TPC/TPSolenoidsDriver.hpp"
#include "TPC/TPSyncDriver.hpp"
#include "TPC/TPTimerDriver.hpp"
#include "TPC/Util.hpp"

static volatile uint8_t waitCount = 0;

static void scheduleTask() {
  TPC::Scheduler::schedule(
    TPC::Scheduler::TaskID::TP_CONTROLLER_SERVICE,
    TPC::Timekeeping::Interval::fromMilliseconds(50)
  );
}

static void cancelTask() {
  TPC::Scheduler::cancel(TPC::Scheduler::TaskID::TP_CONTROLLER_SERVICE);
}

void TPC::TPController::init() {
  // Initialise our peripherals.
  TPC::TPSolenoidsDriver::init();
  TPC::TPSyncDriver::init();
  TPC::TPTimerDriver::init();
  TPC::TPMotorDriver::init();
  TPC::TPSensorsDriver::init();
  TPC::TPDataProvider::init();
}

static bool isOn() {
  return TPC::TPMotorDriver::isOn();
}

static void switchOn() {
  ATOMIC_BLOCK(ATOMIC_RESTORESTATE) {
    if (!isOn()) {
      TPC::TPMotorDriver::on();
      waitCount = TPC::Config::STARTUP_CYCLES;
    }
  }
  scheduleTask();
}

static void switchOff() {
  TPC::TPMotorDriver::off();
  cancelTask();
}

void TPC::TPController::setPrintJob_IE(TPC::Filesystem::Reader reader, uint16_t length) {
  TPC::TPDataProvider::setPrintJob_IE(reader, length);
  switchOn();
}

void TPC::TPController::setFeedOutJob_IE() {
  TPC::TPDataProvider::setFeedOutJob_IE();
  switchOn();
}

void TPC::TPController::clearJob_IE() {
  TPC::TPDataProvider::clearJob_IE();
  switchOff();
}

bool TPC::TPController::readNoTapeSensor() {
  return TPC::TPSensorsDriver::readNoTapeSensor();
}

bool TPC::TPController::readLowTapeSensor() {
  return TPC::TPSensorsDriver::readLowTapeSensor();
}

void TPC::TPController::Hooks::energiseSolenoids_ID() {
  if (!isOn()) {
    return;
  }
  uint8_t waitCount_ = waitCount;
  if (waitCount_ != 0) {
    waitCount = waitCount_ - 1;
    return;
  }
  TPC::Util::MaybeUint8 result = TPC::TPDataProvider::nextByte_ID();
  if (result.hasValue) {
    TPC::TPSolenoidsDriver::energise(result.value);
  } else {
    switchOff();
    TPC::Scheduler::schedule(TPC::Scheduler::TaskID::PRINTING_COMPLETE);
  }
}

void TPC::TPController::Hooks::deenergiseSolenoids_ID() {
  TPC::TPSolenoidsDriver::deenergise();
}

static void checkNoTapeSensor_IE() {
  static bool prevState = false;
  bool currState = TPC::TPController::readNoTapeSensor();
  if (!prevState && currState) {
    TPC::Application::warnNoTapeDuringPrint_IE();
  }
  prevState = currState;
}

static void checkLowTapeSensor_IE() {
  static bool prevState = false;
  bool currState = TPC::TPController::readLowTapeSensor();
  if (!prevState && currState) {
    TPC::Application::warnLowTapeDuringPrint_IE();
  }
  prevState = currState;
}

void TPC::TPController::serviceTask_IE() {
  if (isOn()) {
    checkNoTapeSensor_IE();
    checkLowTapeSensor_IE();
  }
  scheduleTask();
}

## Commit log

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2017-11-22 schematic: fix SYNC voltage divider using a non-E12 resistor value
    [1-tape-punch.sch]
2017-11-22 Connect earth wire and cable shield from tape punch to an internal node named TP_EARTH
    [1-tape-punch.sch]
2017-11-22 Break out TP_EARTH on the power input connector
    TP_EARTH should be wired to the single common grounding point
    (to which mains earth, DC ground and the chassis connection should
    also be wired).
    [3-power.sch]
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2017-11-27 Add first and second iteration of tape punch back panel design
    [back-panel-rev1.fcstd, back-panel-rev2.fcstd]
2017-11-28 Add first revision of PSU cover CAD design
    This is to cover the exposed live terminals on the 28V power supply unit.
    [psu-cover-rev1.dxf]
2017-11-28 Export the back panel CAD design in DXF format
    [back-panel-rev2-export.dxf]
2017-11-28 Re-do back panel design in librecad since freecad keeps crashing
    [back-panel-rev3.dxf]
2017-11-28 Give the directory containing laser cutting designs a better name
    [back-panel-rev1.fcstd, back-panel-rev2-export.dxf, back-panel-rev2.fcstd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]
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2017-11-29 Increase MOSFET gate resistors to 180 ohms
    The new value was calculated by considering the instant at which the
    microcontroller pin goes high. The microcontroller is driving 3.3V at
    one end of the resistor, while the voltage at the MOSFET gate changes
    relatively slowly due to gate capacitance and so is assumed to still be
    0V. We aim for a max current of 18mA (below the microcontroller's limit
    of 20mA), giving a resistance of 3.3V/18mA = 183 ohms.
    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
    [3-power.sch]
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2017-11-30 schematic: add a shield pin to the USB connector symbol
    This is connected to the USB cable shielding (if present), usually
    via the receptacle chassis. The shielding should be wired to ground,
    through an RC filter (to reduce the impact of the shielding acting
    as an antenna on the PCB's ground net).
    [2-microcontroller.sch]
2017-11-30 schematic: wire USB connector shield to ground via RC filter
    See document AVR1017 [1], section 3.3.3.
    [1] http://www.atmel.com/images/doc8388.pdf
    [2-microcontroller.sch]
2017-11-30 schematic: change capacitor 'x-voltage-rating' property to 'x-min-voltage-rating'
    This feels more correct; previously, `x-voltage-rating` was somewhat
    arbitrary (mostly based on the distribution of available capacitors
    fitting the other specs) and unnecessarily restrictive. Specifying a
    minimum voltage rating rather than a required particular value gives
    more freedom when choosing specific parts to order.
    [1-tape-punch.sch, 2-microcontroller.sch, 3-power.sch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]
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2017-12-01 schematic: fix test points being attached to wrong button signals
    nCONFIRM_RAW and nCANCEL_RAW are already accessible as pins 5 and 6
    of CONN1, so it was decided it wasn't necessary to create test
    points for them. Test points TP8 and TP9 were intended to have
    been connected to the corresponding filtered signals nCONFIRM
    and nCANCEL instead.
    [5-test-points.sch]
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2017-12-01 schematic: add test points for STAT_GRN, STAT_RED and TP_EARTH
    STAT_GRN and STAT_RED were initially excluded since they were
    considered accessible from CONN1; however this line of thinking
    doesn't account for failure of the series resistors R6 and R7.
    TP_EARTH is a recently added signal that I forgot to add a test point for.
    [5-test-points.sch]
2017-12-06 schematic: fix device attribute of CONN6 not having been updated when an extra pin was added
    [3-power.sch]
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2017-12-06 schematic: improve LED attributes
    These extra attributes are used for BOM generation.
    [4-controls.sch]
2017-12-06 schematic: change feedback threshold voltage divider resistances to reduce the number of different types of resistor needed by the system
    Now, when the threshold adjust potentiometer is at its central position,
    SYNC_THRESH is 0.16V away from the nominal 8.6V (as compared to 0.07V before
    this change). This is deemed tolerable since the voltage can be adjusted
    back to 8.6V using the potentiometer.
    Previously the 8.2k and 11k resistors were the only ones of their
    kinds used in the design. Additionally, the 11k was the only non-E12
    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
    [1-tape-punch.sch]
2017-12-06 schematic: change debouncing filter resistors to reduce the number of different types of resistor in the system
    The particular value of resistor for the debouncing filter doesn't really
    matter too much. It was easier to change all of these from 33k to 68k,
    rather than to change the one previously existing 68k: R44, which is part
    of the voltage divider for SYNC and can't be changed without also
    changing R47.
    [1-tape-punch.sch, 4-controls.sch]
2017-12-06 schematic: add an x-voltage-rating property to all capacitors
    x-min-voltage-rating is set to the minimum voltage rating necessary
    for the circuit to operate, as determined by the context the
    component is being used in.
    x-voltage-rating is set to the voltage rating of the physical component
    that will be used here, and must be greater than or equal to x-min-voltage-rating.
    This facilitates BOM generation by allowing capacitors with different
    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
    [1-tape-punch.sch, 2-microcontroller.sch, 3-power.sch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]
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2018-01-04 s/geda/kicad/
    KiCAD is actually much nicer to use than gEDA, especially for PCB
    layout.
    * Replace schematic drawn in gschem/gEDA with one drawn in KiCAD
    * First draft of PCB layout
    [1-tape-punch.sch, 2-microcontroller.sch, 3-power.sch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]
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2018-01-12 firmware/TapePunch: allow the current job queue to be extended rather than replaced
    [TapePunch.cpp, main.cpp]
2018-01-12 Rename 'lasercut' to 'mechanical'
    This is because it will shortly contain non-lasercut parts.
    [back-panel-rev1.fcstd, back-panel-rev2-export.dxf, back-panel-rev2.fcstd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]
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2018-01-22 pcb: remove power LEDs
    We have test points and an external power LED, so they're pretty
    redundant. They're also quite power hungry (the resistor for the
    28V LED would dissipate about 300mW constantly), and removing them
    reduces the number of different types of component used on the
    board considerably.
    [power.sch, tape-punch-controller.kicad_pcb]
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2018-01-23 pcb: increase length of isolation gap between high-current and low-current ground plane regions
    [tape-punch-controller.kicad_pcb]
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2018-01-23 pcb: move TP38 reference text so that it is not on top of a via
    [tape-punch-controller.kicad_pcb]
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2018-01-23 pcb: reposition TP17 reference text so that it does not lie on top of a via
    [tape-punch-controller.kicad_pcb]
2018-01-23 pcb: reposition TP23 reference text so that it does not lie on top of a via
    [tape-punch-controller.kicad_pcb]
2018-01-23 pcb: reposition TP30 reference text so that it does not lie on top of a via
    [tape-punch-controller.kicad_pcb]
2018-01-23 pcb: reposition TP29 reference text so that it does not lie on top of a via
    [tape-punch-controller.kicad_pcb]
2018-01-25 pcb: fix SYNC being wired to wrong pin (should be PE2, not PE3)
    [microcontroller.sch, tape-punch-controller.kicad_pcb]
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2018-02-01 pcb: add script to rename gerbers
    Kicad's default filenames cause the university email spam filter
    to flag the files as malware.
    [tape-punch-controller-bottom-copper.gbl, tape-punch-controller-bottom-silk.gbo, tape-punch-controller-bottom-soldermask.gbs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]
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2018-02-06 pcb: change RV1, RV2 and R10 to be 22k instead of 10k
    [controls.sch, feedback-signal.sch, tape-punch-controller.kicad_pcb]
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2018-02-14 firmware: fix UART on XMEGA target not transmitting anything
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2018-02-19 firmware: remove archived source code of earlier iterations
    It's no longer needed.
    [Solenoids.cpp, TapePunch.cpp, main.cpp]
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2018-02-19 firmware/TPC::Drivers::Microcontroller: avoid marking production signature registers as volatile wherever possible
    They're read-only, but gcc doesn't know that.
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2018-02-20 firmware: replace job queue with a module that just holds a single job
    [TapePunch.cpp, main.cpp]
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2018-02-21 firmware/SCSI: fix Read Format Capacities handler using the wrong field of the SCSI command buffer as the allocation length
    Discovered using Usblyzer.
2018-02-21 firmware/SCSI: clear data length residue on error
    If a SCSI command handler returns false while
    commandBlock->DataTransferLength is nonzero, LUFA assumes the
    handler wants to stall for a while and will return the requested
    data later, which is not what we want.
    If, however, commandBlock->DataTransferLength is zero, LUFA
    returns an error response immediately.
2018-02-21 firmware/SCSI/mode sense(6): return an error if an unsupported page is requested
    Currently we don't support any mode sense pages, so this always
    returns an error.
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2018-03-14 pcb: connect negative side of USB ESD protection IC to USB_SHIELD rather than GND, as per document AVR1017
    [controls.sch, feedback-signal.sch, microcontroller.sch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]
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2018-03-16 firmware/Log: fix filename printing
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2018-03-16 firmware/MicrocontrollerDriver: on startup, log what caused the reset
    [main.cpp]
2018-03-16 firmware/TimekeepingDriver: fix microcontroller resetting after ~20 seconds
    The handler for this interrupt was removed a few commits ago, but
    the interrupt wasn't disabled; hence when the interrupt inevitably
    occurs, the default "bad interrupt" ISR is executed, causing a
    microcontroller reset.
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2018-03-16 firmware/ButtonsDriver: fix BOTH->NONE transition, and explain why this special behaviour is needed
2018-03-17 firmware/BlockStorage: use standard boot jump code in the header
    Windows seems to treat this as a fixed signature rather than as
    arbitrary x86 code (or at least it doesn't like what I had in there
    before). Changing to the commonly-accepted EBh 3Ch 90h (a jump to
    just past the end of the FAT header) results in the device working
    fine when plugged into a Windows 10 computer now.
    A side effect is that now weirdness will occur if (for some reason)
    you boot from the device. It would be ideal to print a message and
    halt.
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2018-04-08 firmware/SCSI: remove Prevent/Allow Medium Removal handler
    This command isn't relevant, since the device does not advertise itself
    as being removeable storage. It makes more sense to inform the client
    that the command is invalid/unsupported than to silently ignore it.
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2018-05-12 pcb: fix gerbv project files
